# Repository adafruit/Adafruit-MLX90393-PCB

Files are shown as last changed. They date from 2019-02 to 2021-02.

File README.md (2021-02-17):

## Adafruit Wide-Range Triple-axis Magnetometer - MLX90393 PCB

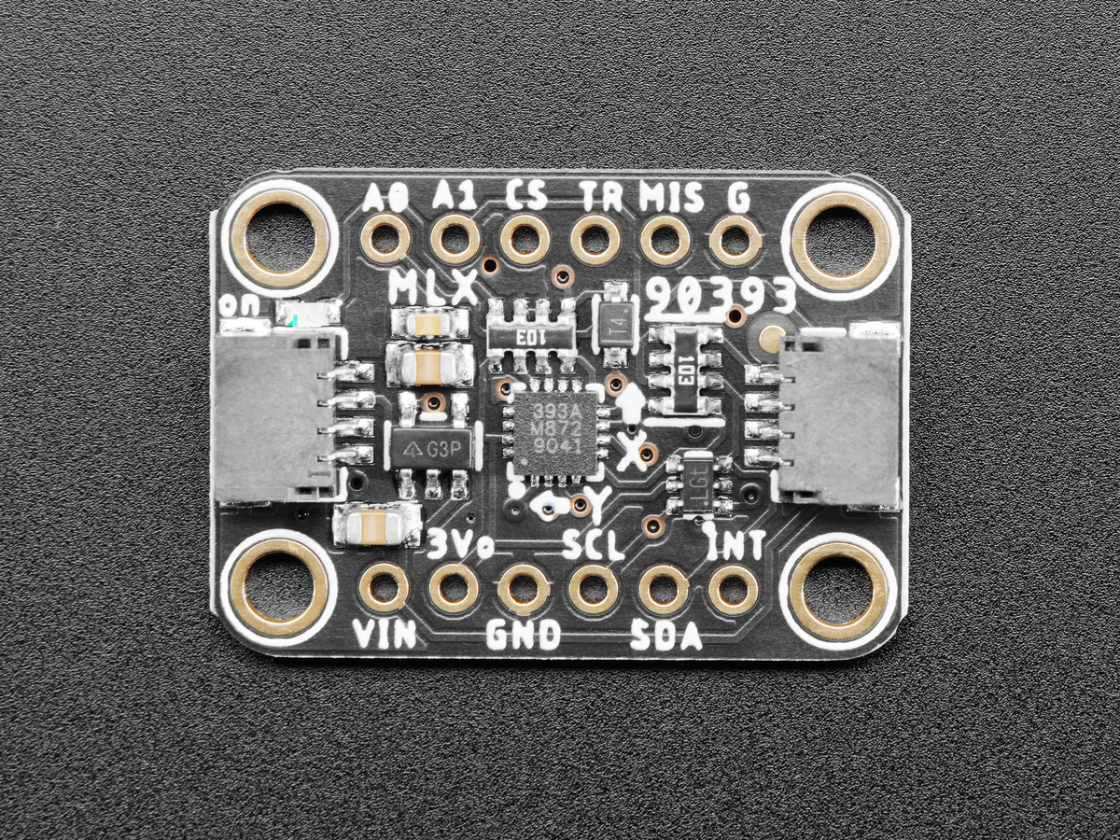
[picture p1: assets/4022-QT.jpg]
<a href="http://www.adafruit.com/products/4022"><br/>
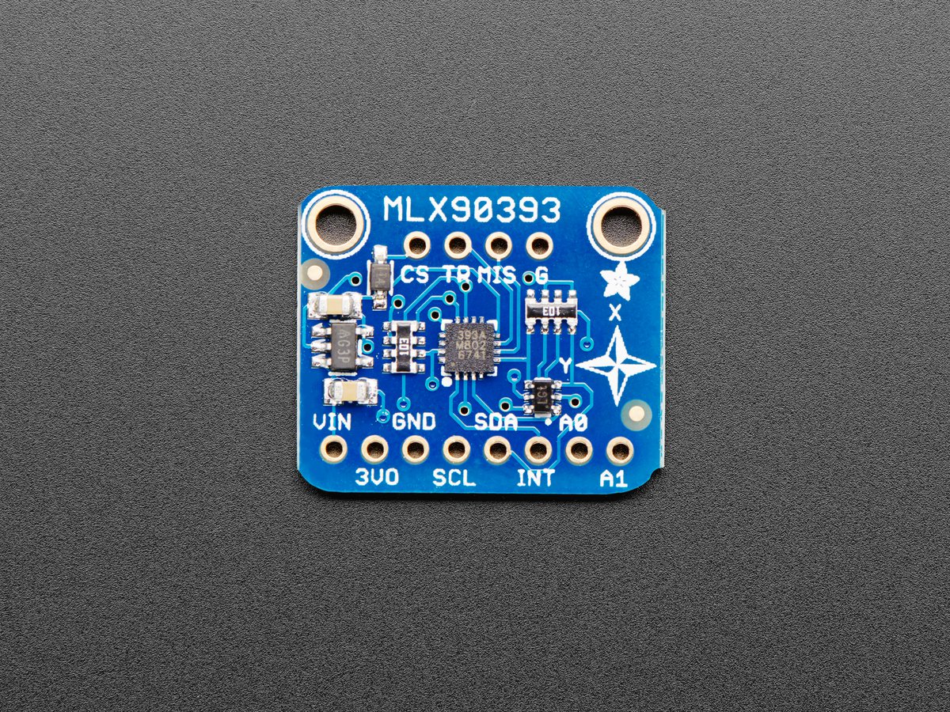
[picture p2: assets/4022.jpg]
<a href="http://www.adafruit.com/products/4022"><br/>
Click here to purchase one from the Adafruit shop</a>

PCB files for the Adafruit Wide-Range Triple-axis Magnetometer - MLX90393. Format is EagleCAD schematic and board layout
* https://www.adafruit.com/product/4022

### Description

Measure the invisible magnetic fields that surround us, with this wide-range magnetometer. The MLX90393 is a wide range magnetic field sensor, that can measure 16-bits in ranges from ±5mT up to ±50mT in all 3 axes.

Compared to most magnetometers, this gives a huge range, which makes it excellent for detecting magnets and magnetic orientation, rather than the Earth's magnetic field. (Magnets have a much stronger field that overwhelms most magnetometers that would normally be used for orientation with respect to the North Pole)

To make it easy to use, we've placed this tiny little sensor onto a breakout board, with a 3.3V power supply and level shifter. This makes it easy to use with any 3 or 5V microcontroller. Our Arduino and CircuitPython code will get you started in a jiffy, with I2C communication to the sensor. You will be readin' out those Gauss's in minutes! With the address select pins you can have up to 4 sensors on one I2C bus.

Comes as a fully assembled and tested breakout board with a small piece of header for use with a breadboard. As if that weren't enough, we've now also added SparkFun qwiic compatible STEMMA QT connectors for the I2C bus so you don't even need to solder the I2C and power lines. Just wire up to your favorite micro using a STEMMA QT adapter cable. The Stemma QT connectors also mean the MLX90393 can be used with our various associated accessories. QT Cable is not included, but we have a variety in the shop.

**Specifications**
The MLX90393 has the following key technical specifications:

 * 16-bit output on all three (XYZ) magnetic field sensors
 * An unusually large dynamic range of **5-50** mT (1 mT or millitesla = 10 G or Gauss).
 * By comparison, the LSM303DLHC saturates at +/-8.1 G (0.81 mT) at maximum range setting.
 * Up to ~500 Hz sample rate (Based on OSR=0, DIG_FILT=2, HALLCONF=0xC for **1.84ms** conversion time. See 15.1.5 HALLCONF [3:0] in the datasheet for details.)
 * User-adjustable I2C address to allow multiple sensors in your project (two I2C ADDR pins for four possible I2C addresses).

### License

Adafruit invests time and resources providing this open source design, please support Adafruit and open-source hardware by purchasing products from [Adafruit](https://www.adafruit.com)!

Designed by Limor Fried/Ladyada for Adafruit Industries.

Creative Commons Attribution/Share-Alike, all text above must be included in any redistribution. See license.txt for additional details.

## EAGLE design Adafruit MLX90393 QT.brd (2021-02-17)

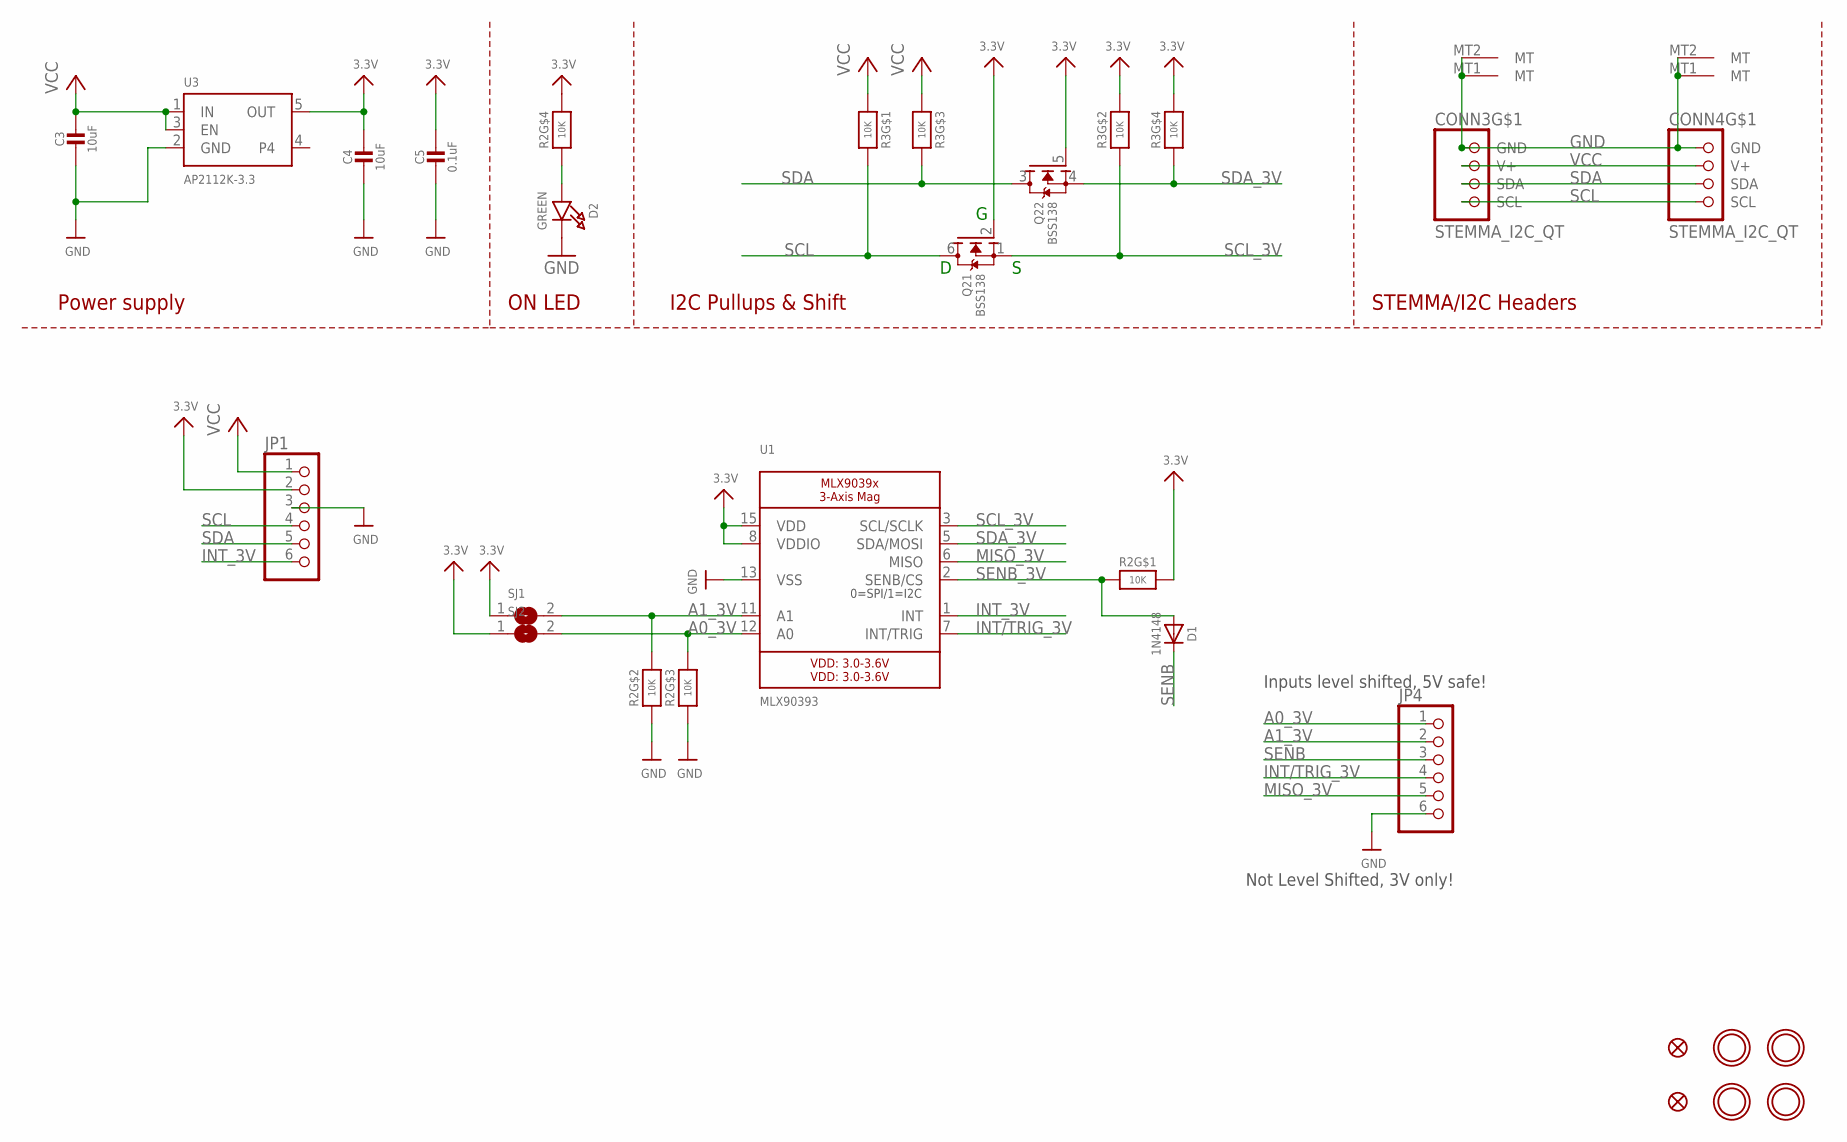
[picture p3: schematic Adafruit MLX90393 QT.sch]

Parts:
C3, C4: 10uF; 0805-NO
C5: 0.1uF; 0603-NO
CONN3, CONN4: STEMMA_I2C_QT; JST_SH4
D1: 1N4148; SOD-323_MINI
D2: GREEN; CHIPLED_0603_NOOUTLINE
FID2, FID4: FIDUCIAL_1MM
JP1, JP4: HEADER-1X670MIL; 1X06_ROUND_70
Q2: BSS138; SOT363
R2: 10K; RESPACK_4X0603_NO
R3: 10K; RESPACK_4X0603
SJ1, SJ2: SOLDERJUMPER; SOLDERJUMPER_ARROW_NOPASTE
U1: MLX90393; QFN16_3MM
U3: AP2112K-3.3; SOT23-5
U$33, U$34, U$36, U$37: MOUNTINGHOLE2.5; MOUNTINGHOLE_2.5_PLATED

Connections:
3.3V: C4.1, C5.1, JP1.2, Q2.2 (G), Q2.5 (G), R2.5 (2), R2.8 (2), R3.2 (1), R3.4 (1), SJ1.1, SJ2.1, U1.8 (VDDIO), U1.15 (VDD), U3.5 (OUT)
A0_3V: JP4.1, R2.6 (2), SJ2.2, U1.12 (A0)
A1_3V: JP4.2, R2.7 (2), SJ1.2, U1.11 (A1)
GND: C3.2, C4.2, C5.2, CONN3.1 (GND), CONN3.MT1 (MT), CONN3.MT2 (MT), CONN4.1 (GND), CONN4.MT1 (MT), CONN4.MT2 (MT), D2.C, JP1.3, JP4.6, R2.2 (1), R2.3 (1), U1.13 (VSS), U3.2 (GND)
INT/TRIG_3V: JP4.4, U1.7 (INT/TRIG)
INT_3V: JP1.6, U1.1 (INT)
MISO_3V: JP4.5, U1.6 (MISO)
unnamed: D2.A, R2.4 (1)
SCL: CONN3.4 (SCL), CONN4.4 (SCL), JP1.4, Q2.6 (D), R3.8 (2)
SCL_3V: Q2.1 (S), R3.7 (2), U1.3 (SCL/SCLK)
SDA: CONN3.3 (SDA), CONN4.3 (SDA), JP1.5, Q2.3 (D), R3.6 (2)
SDA_3V: Q2.4 (S), R3.5 (2), U1.5 (SDA/MOSI)
SENB: D1.C, JP4.3
SENB_3V: D1.A, R2.1, U1.2 (SENB/CS)
VCC: C3.1, CONN3.2 (V+), CONN4.2 (V+), JP1.1, R3.1, R3.3 (1), U3.1 (IN), U3.3 (EN)

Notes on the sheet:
I2C Pullups & Shift
STEMMA/I2C Headers
ON LED
Power supply
Not Level Shifted, 3V only!
Inputs level shifted, 5V safe!

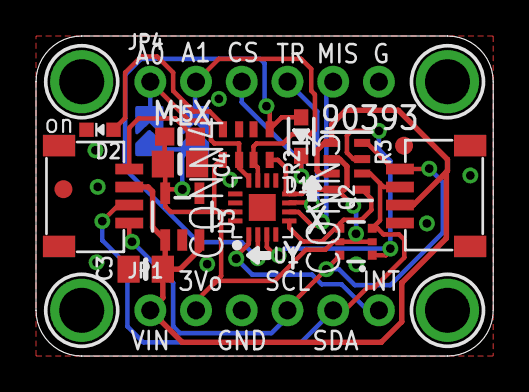
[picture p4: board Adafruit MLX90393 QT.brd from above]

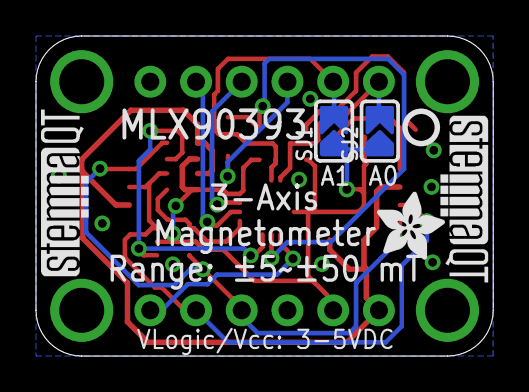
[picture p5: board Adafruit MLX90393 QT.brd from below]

Board: 2 copper layers, 25.4 x 17.8 mm, 26 parts (6 on the bottom side), 15 nets.

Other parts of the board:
U$18: PCBFEAT-REV-040
U$39: ADAFRUIT_3.5MM
U$41, U$42: STEMMAQT

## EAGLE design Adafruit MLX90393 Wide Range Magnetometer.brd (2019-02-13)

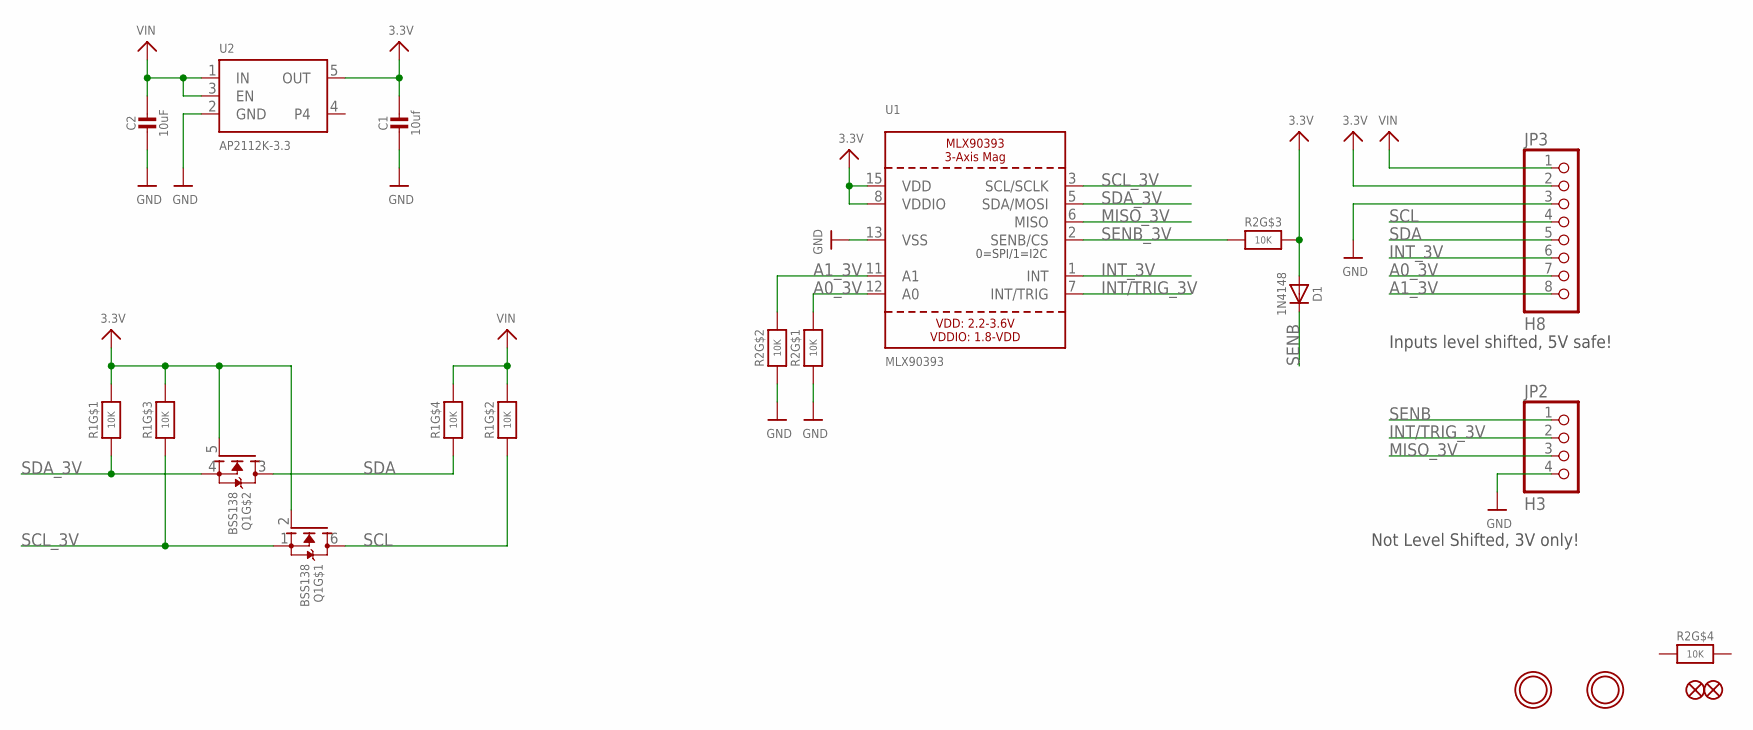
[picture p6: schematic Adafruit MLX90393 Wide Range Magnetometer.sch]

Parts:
C1: 10uf; 0805_10MGAP
C2: 10uF; 0805_10MGAP
D1: 1N4148; SOD-323
FID1, FID3: FIDUCIAL_1MM
JP2: H3; 1X04_ROUND
JP3: H8; 1X08_ROUND
Q1: BSS138; SOT363
R1, R2: 10K; RESPACK_4X0603_NO
U1: MLX90393; QFN16_3MM
U2: AP2112K-3.3; SOT23-5
U$19, U$23: MOUNTINGHOLE2.5; MOUNTINGHOLE_2.5_PLATED

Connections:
3.3V: C1.1, D1.A, JP3.2, Q1.2 (G), Q1.5 (G), R1.6 (2), R1.8 (2), R2.6 (2), U1.8 (VDDIO), U1.15 (VDD), U2.5 (OUT)
A0_3V: JP3.7, R2.8 (2), U1.12 (A0)
A1_3V: JP3.8, R2.7 (2), U1.11 (A1)
GND: C1.2, C2.2, JP2.4, JP3.3, R2.1, R2.2 (1), U1.13 (VSS), U2.2 (GND)
INT/TRIG_3V: JP2.2, U1.7 (INT/TRIG)
INT_3V: JP3.6, U1.1 (INT)
MISO_3V: JP2.3, U1.6 (MISO)
SCL: JP3.4, Q1.6 (D), R1.2 (1)
SCL_3V: Q1.1 (S), R1.3 (1), U1.3 (SCL/SCLK)
SDA: JP3.5, Q1.3 (D), R1.4 (1)
SDA_3V: Q1.4 (S), R1.1, U1.5 (SDA/MOSI)
SENB: D1.C, JP2.1
SENB_3V: R2.3 (1), U1.2 (SENB/CS)
VIN: C2.1, JP3.1, R1.5 (2), R1.7 (2), U2.1 (IN), U2.3 (EN)

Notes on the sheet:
Not Level Shifted, 3V only!
Inputs level shifted, 5V safe!

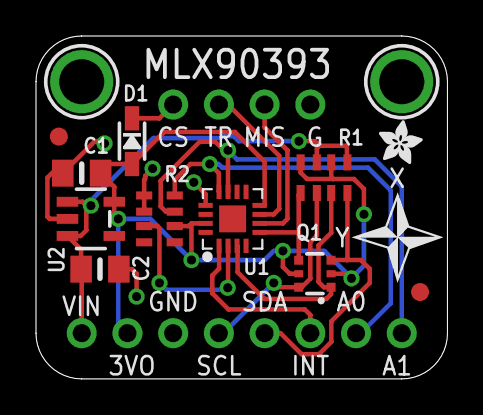
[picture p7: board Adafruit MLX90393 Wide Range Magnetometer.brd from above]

Board: 2 copper layers, 22.9 x 19.1 mm, 17 parts (1 on the bottom side), 14 nets.

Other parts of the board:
U$3: SYMBOL_COMPASSXY_5MM
U$18: PCBFEAT-REV-040
U$21: ADAFRUIT_2.5MM

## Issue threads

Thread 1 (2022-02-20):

Silkscreen on PCB for X, Y axes is backwards

ShawnHymel, 2022-02-20:
Not sure if this is the best place to post this issue. If you do a refresh or v2 of the PCB, please note that the silkscreen for the X and Y axes are reversed. According to the datasheet, X should point from bottom of chip to the pin 1 marker. Y should be from pin 1 marker to the left side of the chip.

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

The PCB silkscreen has those 2 arrows reversed.

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

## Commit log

2019-02-13 Add PCB files.
    [Adafruit MLX90393 Wide Range Magnetometer.brd, Adafruit MLX90393 Wide Range Magnetometer.sch]
2019-07-17 updated to use cookiecutter for pcb repos
2021-02-17 Add board files.
    [Adafruit MLX90393 QT.brd, Adafruit MLX90393 QT.sch]

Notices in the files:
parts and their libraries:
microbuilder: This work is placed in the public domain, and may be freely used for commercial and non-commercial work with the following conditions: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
